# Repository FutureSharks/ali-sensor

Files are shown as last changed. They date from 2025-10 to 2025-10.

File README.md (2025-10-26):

# ali-sensor

A multi-sensor device for [Home Assistant](https://www.home-assistant.io/) built around cheap parts from [AliExpress](https://aliexpress.com/). This project is essentially a [PCB design](pcb) and [ESPHome](https://esphome.io/) configuration that allows you to build a customisable device that could detect presence and measure light, CO₂, temperature, humidity, VOCs and more. You can choose a selection of sensors available from your favourite marketplace of questionable but cheap goods.

The PCB is designed around an [ESP32-C6 Super Mini](https://www.espboards.dev/esp32/esp32-c6-super-mini/) and features:

- Space for a single [HLK-LD2410C](https://www.hlktech.net/index.php?id=1095) Human Presence sensor
- 2x I2C sensor stacks where many different sensors can be connected
- 4x GPIO out
- I2C bus power selector for 3.3V or 5V
- Power connector or alternatively use the USB-C connector from the ESP32-C6

## Example build

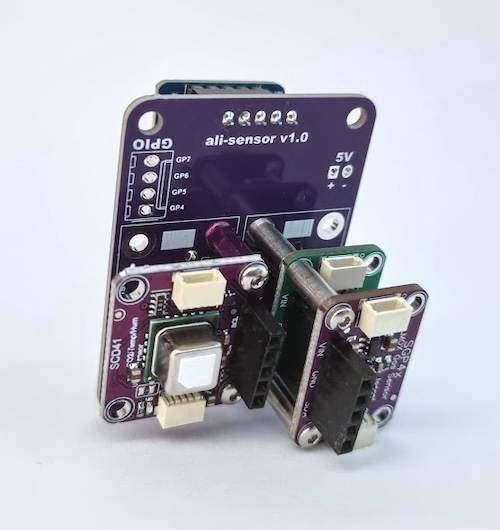
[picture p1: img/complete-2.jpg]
complete-
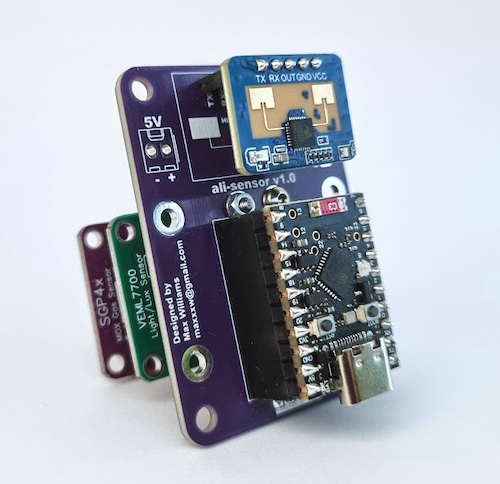
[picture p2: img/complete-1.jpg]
complete-1
 

This example build measures Lux, CO₂ , VOCs, NOx index, temperature, humidity, presence and motion using the following devices from AliExpress:

- ESP32-C6 Super Mini (4.90€)
- HLK-LD2410C Human Presence & Distance Detection Radar Sensor Module (3.70€)
- SGP41 VOC and NOx sensor (12€)
- SCD41 CO₂ sensor (23€)
- VEML7700 High accuracy ambient light sensor (3.85€)

Total cost is about 47€, very reasonable given that it includes high quality gas and CO₂ sensors.

## The sensors

There are a number of suitable sensors from not just AliExpress but also [Adafruit](https://www.adafruit.com/) (actually I think they created the layout/footprint of these sensors). Look for the sensors that have this 5 pin and mounting hole layout:

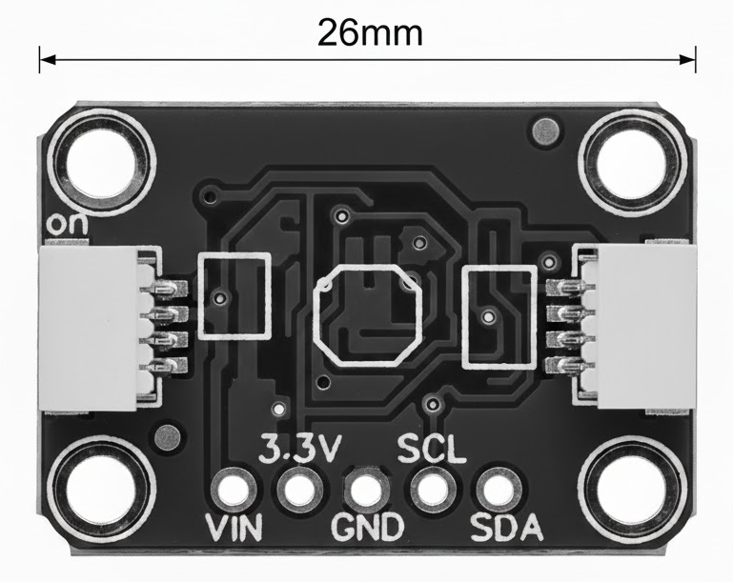
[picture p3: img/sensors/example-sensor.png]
example-sensor


Some examples I have found:

- SGP41 VOC and NOx sensor (AliExpress)
- SCD41 CO₂ sensor (AliExpress)
- VEML7700 light sensor (AliExpress)
- SGP30 indoor air quality gas sensor (AliExpress)
- SHT45 Precision Temp & Humidity (Adafruit)
- Si7021 Temperature & Humidity Sensor (Adafruit)
- SHTC3 Temperature & Humidity (Adafruit)
- QMC5883P Triple axis agnetometer (Adafruit)
- MMC5603 Triple axis agnetometer (Adafruit)
- TLV493D Triple-Axis Magnetometer (Adafruit)
- MS8607 Pressure Humidity Temperature (Adafruit)

Some photos of these sensors are collected in [img/sensors](img/sensors) to make finding the correct version on AliExpress easier.

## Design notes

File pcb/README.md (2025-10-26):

# PCB and schematic

The PCB and schematic are made with [KiCad](https://www.kicad.org/). The project files are in [ali-sensor](ali-sensor)

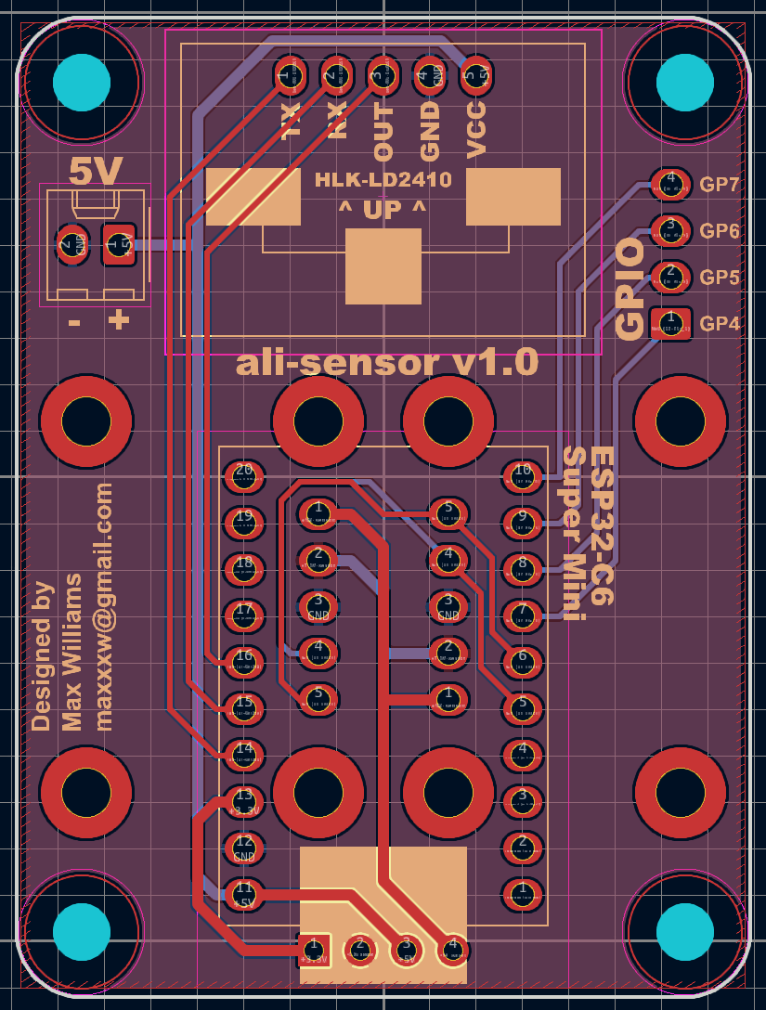
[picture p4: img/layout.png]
layout


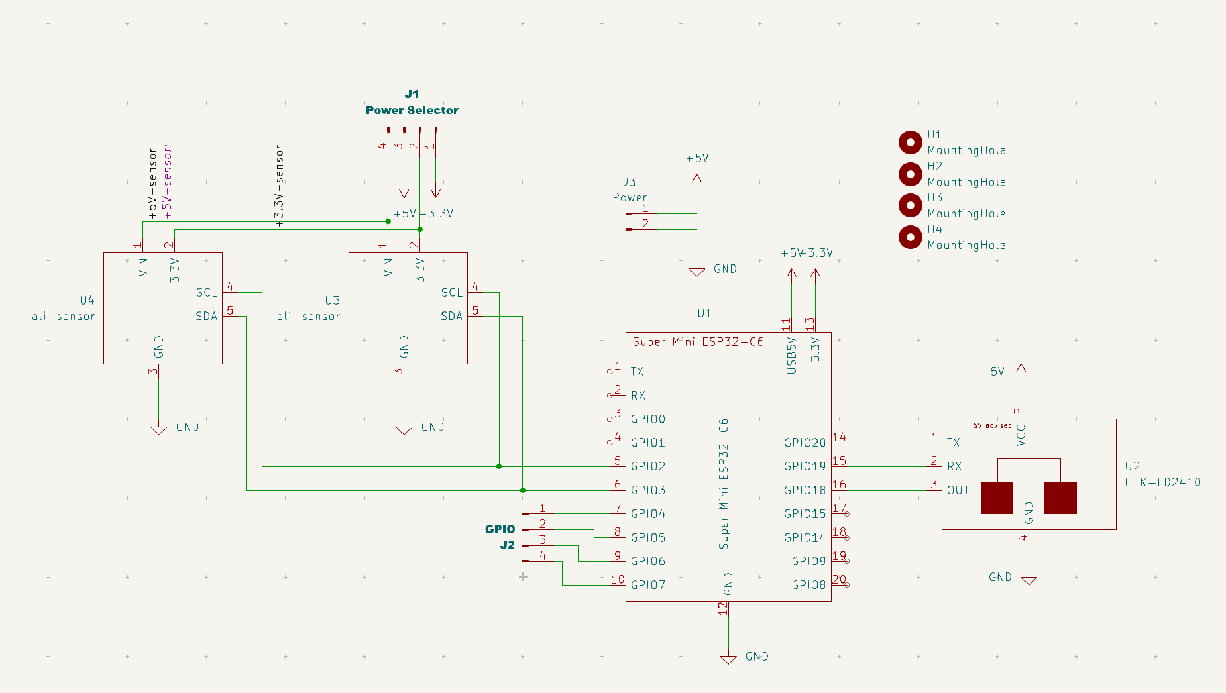
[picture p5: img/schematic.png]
Schematic


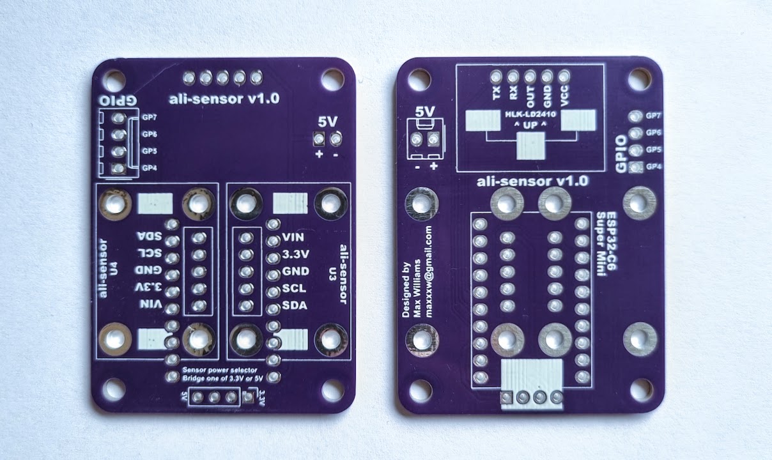
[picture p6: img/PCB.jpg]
PCB


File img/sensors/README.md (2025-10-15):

# Example sensors

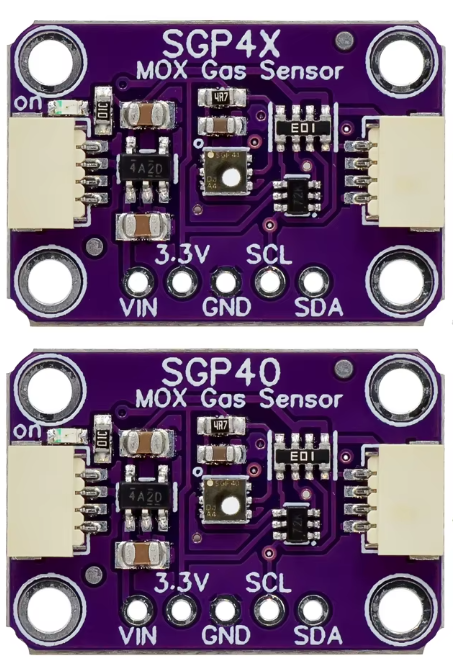
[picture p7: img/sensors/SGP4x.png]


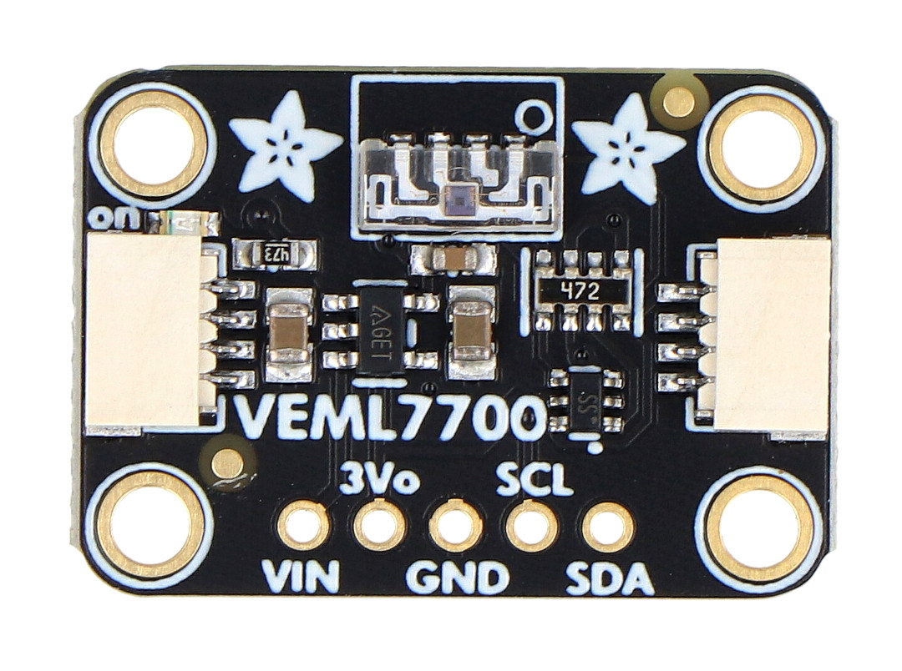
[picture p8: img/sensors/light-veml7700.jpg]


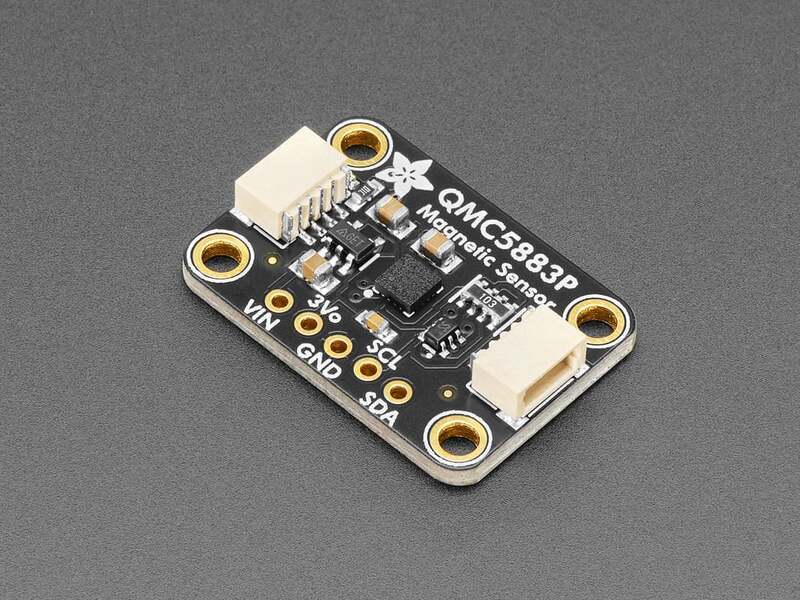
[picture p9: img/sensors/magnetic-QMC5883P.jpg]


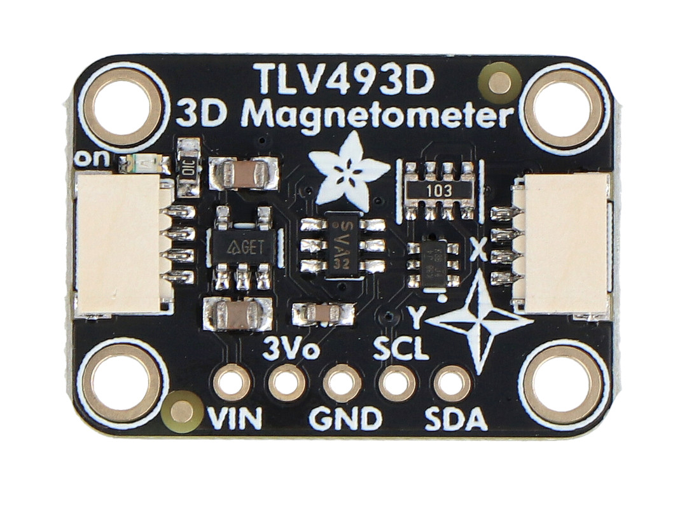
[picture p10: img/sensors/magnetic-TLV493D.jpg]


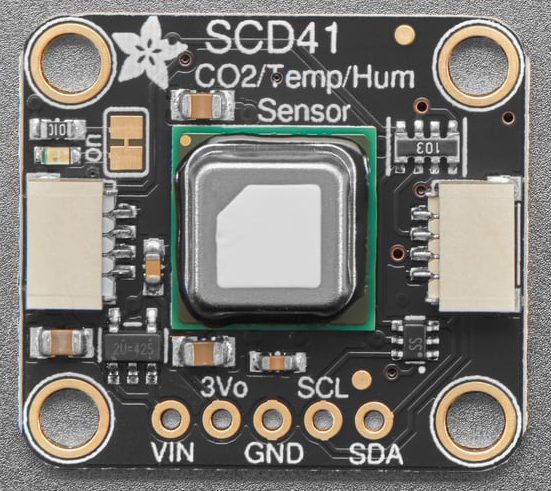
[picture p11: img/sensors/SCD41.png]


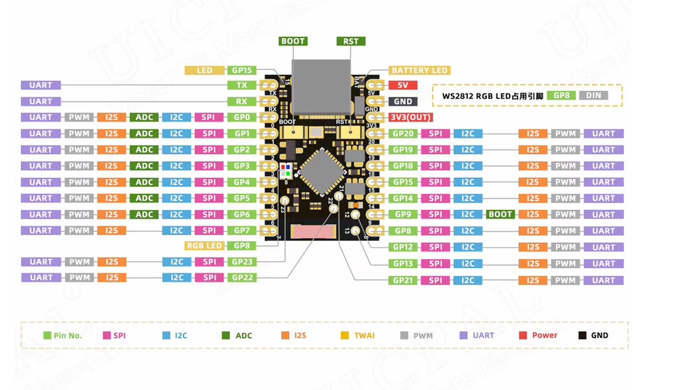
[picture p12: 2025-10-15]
img/esp32-c6-super-mini-pinout.png

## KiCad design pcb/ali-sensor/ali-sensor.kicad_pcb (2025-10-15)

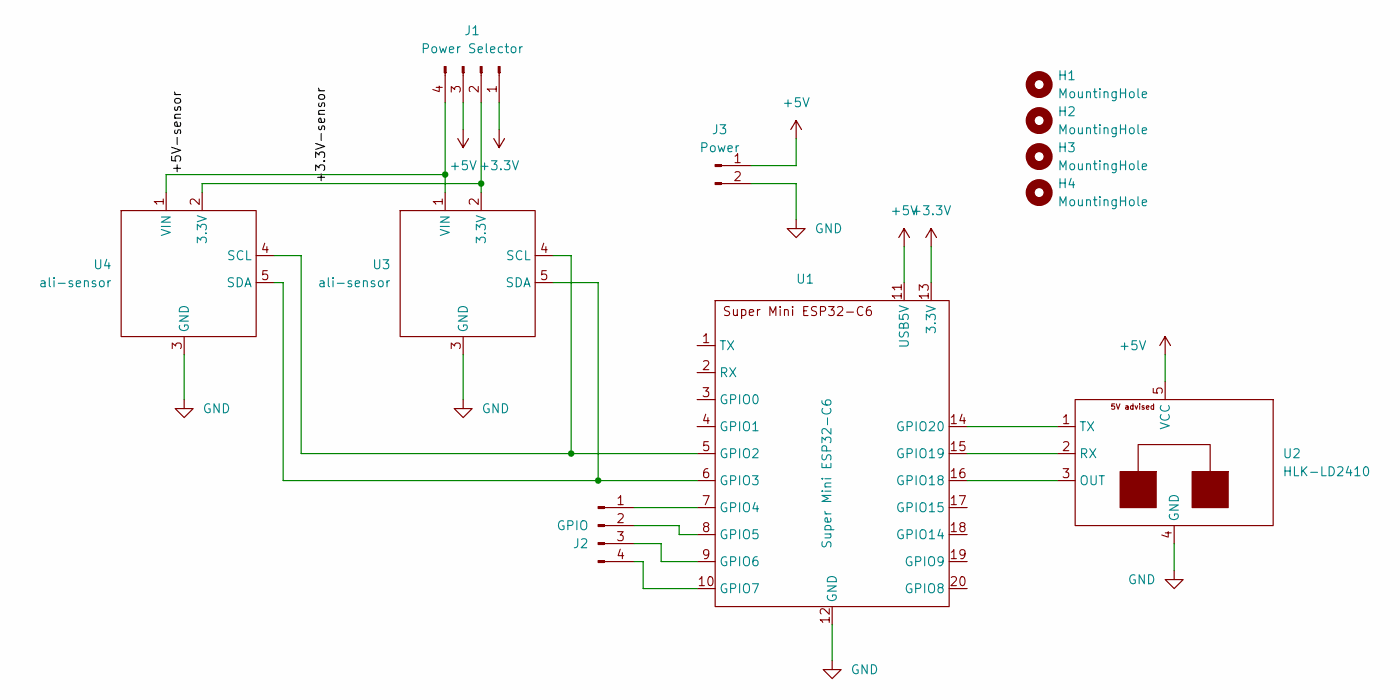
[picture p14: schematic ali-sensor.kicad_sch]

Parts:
H1, H2, H3, H4: MountingHole; MountingHole_3.2mm_M3
J1: Power Selector; PinHeader_1x04_P2.54mm_Vertical
J2: GPIO; Molex_KK-254_AE-6410-04A_1x04_P2.54mm_Vertical
J3: Power; Molex_KK-254_AE-6410-02A_1x02_P2.54mm_Vertical
U1: Super Mini ESP32-C6; ESP32-C6
U2: HLK-LD2410; HLK-LD2410C
U3, U4: ali-sensor

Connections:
+3.3V: J1.1, U1.13 (3.3V)
+5V: J1.3, J3.1, U1.11 (USB5V), U2.5 (VCC)
/+3.3V-sensor: J1.2, U3.2 (3.3V), U4.2 (3.3V)
/+5V-sensor: J1.4, U3.1 (VIN), U4.1 (VIN)
GND: J3.2, U1.12 (GND), U2.4 (GND), U3.3 (GND), U4.3 (GND)
unnamed: J2.1, U1.7 (GPIO4)
unnamed: J2.2, U1.8 (GPIO5)
unnamed: J2.3, U1.9 (GPIO6)
unnamed: J2.4, U1.10 (GPIO7)
unnamed: U1.5 (GPIO2), U3.4 (SCL), U4.4 (SCL)
unnamed: U1.6 (GPIO3), U3.5 (SDA), U4.5 (SDA)
unnamed: U1.16 (GPIO18), U2.3 (OUT)
unnamed: U1.15 (GPIO19), U2.2 (RX)
unnamed: U1.14 (GPIO20), U2.1 (TX)

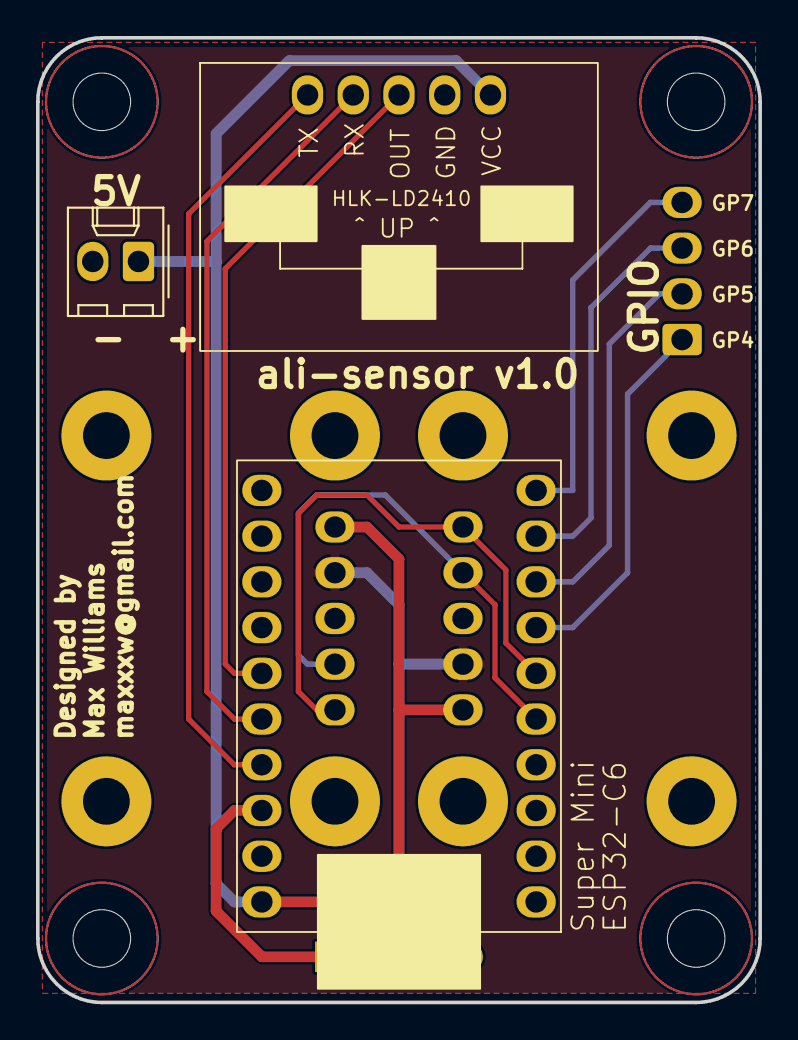
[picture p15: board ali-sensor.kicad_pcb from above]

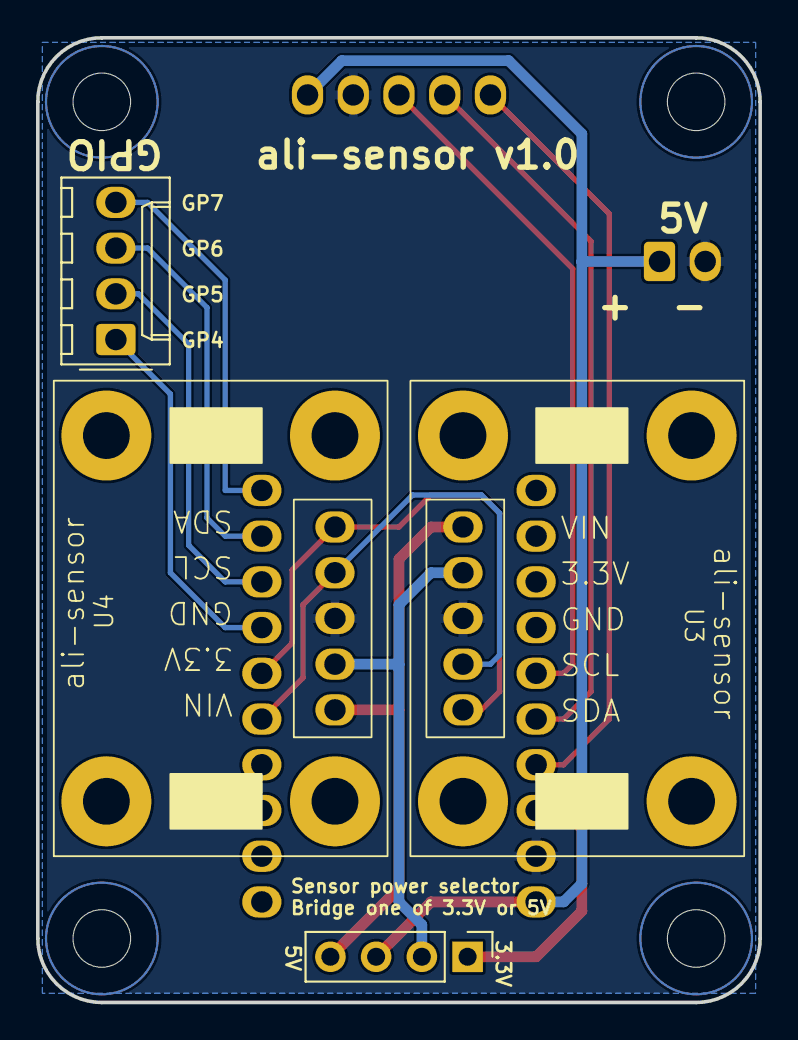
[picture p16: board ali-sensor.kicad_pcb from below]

Board: 2 copper layers, 40.1 x 53.6 mm, 11 parts (4 on the bottom side), 14 nets.

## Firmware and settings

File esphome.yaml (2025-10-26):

esphome:
  name: ali-sensor
  friendly_name: ali-sensor
  on_boot:
    then:
      - switch.turn_off: btswitch

esp32:
  board: esp32-c6-devkitc-1
  framework:
    type: esp-idf

logger:

light:
  - platform: esp32_rmt_led_strip
    rgb_order: GRB
    pin: GPIO8
    num_leds: 1
    chipset: ws2812
    name: "Onboard RGB LED"
    effects:
      - random:
      - flicker:
      - addressable_rainbow:
  - platform: binary
    name: "Onboard blue LED"
    output: blue_led
    restore_mode: RESTORE_DEFAULT_OFF

output:
  - id: blue_led
    platform: gpio
    pin: GPIO15

uart:
  baud_rate: 256000
  rx_pin: 20
  tx_pin: 19

ld2410:

binary_sensor:
  - platform: ld2410
    has_target:
      name: Presence
    has_moving_target:
      name: Moving Target
    has_still_target:
      name: Still Target
    out_pin_presence_status:
      name: out pin presence status

switch:
  - platform: ld2410
    engineering_mode:
      name: "engineering mode"
    bluetooth:
      name: "control bluetooth"
      id: btswitch

i2c:
  sda: 3
  scl: 2
  frequency: 200kHz

sensor:
  - platform: sgp4x
    voc:
      name: "VOC Index"
    nox:
      name: "NOx Index"
  - platform: veml7700
    address: 0x10
    update_interval: 10s
    ambient_light: "Ambient light"
  - platform: scd4x
    co2:
      name: "CO2"
    temperature:
      name: "Temperature"
    humidity:
      name: "Humidity"
